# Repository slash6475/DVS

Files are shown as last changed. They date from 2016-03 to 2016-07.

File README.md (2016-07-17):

# DVS: Electronic Devil Stick
This project is an introduction to how to build quickly a native IP-based connected object on tiny platform. 
DVS is a simple electronic board composed of a 8 bits- microcontroller with Zigbee tranceiver, an accelerometer and some leds on child boards with an external button.
The software is implemented on Contiki OS, this micro-kernel dedicated to the Internet Of Thing allows 6LoWPAN networking (uIP stack with RPL for mesh network routing),
file system management to store data on flash or eeprom memories, shell interface over serial line, embedded webserver and more.

A simple Javascript page allows to design programs of RGB led sequences and to load them on the DVS platform over HTTP.
The programs are stored into the DVS file system and play on the leds according to the selected program by the external button.
In addition, the accelerometer and wireless communication can be used to control the leds. 
The wireless communication based on 6LoWPAN and HTTP can be operated by any other DVS platforms or computers.
Based on these features, a lot of scenarios and applications can be imagined. 



# Software
Contiki OS has a software architecture which facilitates the encapsulation of drivers and applications into independent containers.
Hence each component of DVS software is independent which facilitates implementation, modularity and code re-use.
Thanks to the shell over the serial line, it is possible to test the drivers of RGB leds and accelerometers, to manage the Webserver (start/stop) and the file system formating such as presented in following video.

(https://youtu.be/-myyth4NgPw)

## Shell Interface
Open the serial line over USB interface: 
```
minicom -D /dev/ttyUSB0 -b 19200
```
At booting time, different information on Contiki OS and DVS software configurations are provided such as networking, boot sequence, etc.
The command help provides the list of available commands:
```
neopixel test
neopixel ID_led R G B
mpu6050 start | stop
...
help
ps
kill
killall

```
## Programming
The software is implemented in C language and cross-platforms (MSP, AVR, ARM, X86, PIC, etc). The compilation must be executed in main project folder.
```
cd contiki-2.6/examples/dvs_main/
```
### Compilation
```
make all TARGET=avr-atmega128rfa1
avr-size --mcu=atmega128rfa1 dvs-main.avr-atmega128rfa1  -C
```

### Preparation
It is preferred to remove fuse and eeprom section to avoid to break fuse configuration and to erase programs stored in memories.
```
avr-objcopy -O ihex -R .eeprom -R .fuse -R .signature dvs-main.avr-atmega128rfa1 dvs-main.hex
```

### Loading
Example to load the program over ISP connector with a JTAG2 device.
```
sudo avrdude -p atmega128rfa1 -c jtag2isp -P usb -Uflash:w:dvs-main.hex
```
### 

## Arduino encapsulation
The DVS uses the accelerometer MPU6050 and the RGB leds Neopixel which have their librairy implemented in Arduino C++. 
Intead of implementing new librairies for Contiki OS, it is possible to link them dynamically at compilation step. 
Build a dvs.ino file with Arduino style and compile it, then remove the main.o and encapsulate it in a dynamic library.
More details in (contiki-2.6/apps/dvs)
```
avr-ar -cvq dvs_arduino.a *.o
```

In DVS Makefile of Contiki:
```
PROJECT_LIBRARIES=../../apps/dvs/libs/dvs_arduino.a
```

# Web Apps
The Web Interface is a simple javascript page which allows to generate and sequence chunk such as presented below. 
The number of program is not limited, however the sum of all sequences of all programs should be lower than file system size (4Kb).
Programs can be deleted individually, a long pressure on external button (> 20s) formats the file system.
```
OPERATION:TIME:RR1GG1BB1RR2GG2BB2 ...
add:0:001000000000000000000000ff0000ff0000000000000000000000000000000000000000ff0000ff0000000000000000000000
```



# Hardware

The master boards is composed of AVR Atmega128rfa1 with IEEE 802.15.4 radio transceiver, an accelerometer MPU6050 an an FTDI chipset for USB serial line. The external connectors provides pins to control Neopixel leds (16 in default child boards) and power stage of 4 AAAA batteries with their charger circuit based on LM317.
More detail and Eagle files in (/hardware).

## Scheme and PCB of Master Board



## Results



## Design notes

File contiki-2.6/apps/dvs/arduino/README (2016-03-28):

The arduino library should be compiled into an archive library .a and integrated during Contiki OS compilation.

1) Compile the arduino program by a traditionnal way
2) Get ALL object files, including ones of the libraries execpted the main.cpp.o because we will use one of Contiki
3) If some implemented functions in Arduino should be in Contiki, their prototype should be declared in extern "C" {} section of Arduino.h
4) Build the archive avr-ar -cvq dvs_arduino.a *.o
5) Move the archive libs folder to be included in Contiki compilation process thanks to Makefile.dvs

!! Trouble, some conflicts can occur about timers and other hardware component between Contiki and Arduino.

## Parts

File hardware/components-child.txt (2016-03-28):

Partlist

Exported from BatonDuDiable-leds.sch at 02/02/2016 17:00:40

EAGLE Version 7.4.0 Copyright (c) 1988-2015 CadSoft

Assembly variant: 

Part     Value          Device         Package         Library                    Sheet

BAT1                    BATTERYAAA-KIT BATTERY-AAA-KIT SparkFun-Electromechanical 1
BAT2                    BATTERYAAA-KIT BATTERY-AAA-KIT SparkFun-Electromechanical 1
LED1     WS2812B        WS2812B        WS2812B         WS2812                     1
LED2     WS2812B        WS2812B        WS2812B         WS2812                     1
LED3     WS2812B        WS2812B        WS2812B         WS2812                     1
LED4     WS2812B        WS2812B        WS2812B         WS2812                     1
LED5     WS2812B        WS2812B        WS2812B         WS2812                     1
LED6     WS2812B        WS2812B        WS2812B         WS2812                     1
LED7     WS2812B        WS2812B        WS2812B         WS2812                     1
LED8     WS2812B        WS2812B        WS2812B         WS2812                     1
SV1                     FE05-2W        FE05-2W         con-lsta                   1
SV2                     FE05-1         FE05-1          con-lsta                   1

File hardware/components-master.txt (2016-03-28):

Partlist

Exported from BatonDuDiable.brd at 02/02/2016 17:00:12

EAGLE Version 7.4.0 Copyright (c) 1988-2015 CadSoft

Assembly variant: 

Part      Value          Package           Library     Position (inch)       Orientation

A                        FE05-2W           con-lsta    (0.4 1.35)            R270
B                        FE05-2W           con-lsta    (2.75 1.35)           R90
B1        BALUN0805      BALUN             SparkFun    (2.45 1.5)            MR0
C1        1uF            C0603             rcl         (0.7 1.15)            R0
C2        0.1uF          0603-CAP          SparkFun    (0.7 1.25)            R0
C3        0.1uF          0603-CAP          SparkFun    (1.252 1.294)         MR90
C4        0.1uF          0603-CAP          SparkFun    (0.65 1.35)           R0
C5        10uF           0603-CAP          SparkFun    (1.95 1.25)           R270
C6        10 nF          0603-CAP          SparkFun    (1.672 1.575)         MR180
C7        1uF            0805              SparkFun    (1.25 1.5)            MR270
C8        1uF            0805              SparkFun    (1.15 1.5)            MR270
C9        12pF           0603-CAP          SparkFun    (0.9 1.2)             MR180
C10       12pF           0603-CAP          SparkFun    (1.1 1.2)             MR0
C11       12pF           0603-CAP          SparkFun    (1.9 1.2)             MR0
C12       12pF           0603-CAP          SparkFun    (1.9 1.3)             MR0
C13       22pF           0603-CAP          SparkFun    (2.3 1.5)             MR0
C14       22pF           0603-CAP          SparkFun    (2.45 1.35)           MR0
C15       0.47pF         0603-CAP          SparkFun    (2.45 1.2)            MR90
C16       4.7uF          0603-CAP          SparkFun    (0.85 1.5)            R90
C17       1uF            0805              SparkFun    (1.85 1.25)           R90
C18       0.1uF          0603-CAP          SparkFun    (0.8 1.35)            R0
C19       47 pF          0603-CAP          SparkFun    (0.7 1.25)            MR180
C20       47 pF          0603-CAP          SparkFun    (0.7 1.15)            MR180
IC1       FT230XQ        QFN16             ftdichip    (1 1.45)              R0
LED2                     CHIPLED_0603      led         (2.45 1.4)            R0
MICRO-USB USB-CONNECTOR  MICRO-USB-435-645 myrobotics2 (1 1.25)              R0
QUARTZ1   753-7203       753-7203          myrobotics2 (1 1.45)              MR90
QUARTZ2   QUARTZ32768    QUARTZ32768       myrobotics2 (1.9 1.4)             MR270
R1        10k            0603-RES          SparkFun    (2.05 1.5)            R180
R2        5.1K           0603-RES          SparkFun    (2.05 1.5)            MR270
R3        1.1k           R0603             rcl         (2.45 1.25)           R90
R4        5.1K           0603-RES          SparkFun    (2.15 1.5)            MR270
R50       10k            R0603             rcl         (1.85 1.45)           R90
R51       10             R0603             rcl         (0.8 1.35)            MR0
R53       10             R0603             rcl         (0.65 1.35)           MR0
SCL                      1X01              pinhead     (1.489 1.112)         R0
SDA                      1X01              pinhead     (1.589 1.112)         R0
SPI                      2X03              pinhead     (2.201 1.223)         R90
U$1       MPU-6050       QFN.24.4X4        MPU6050     (1.55 1.35)           MR0
U$7       MIC5366-2.8YMT SOT23-5           SparkFun    (0.7 1.5)             MR0
U1        ATMEGA128RFA1  QFN-64            SparkFun    (1.55 1.35)           R0
Y1        ANTENNA2SMD5   ANTENNA-CHIP5     SparkFun    (2.201 1.16)          MR0

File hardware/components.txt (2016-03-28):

Partlist

Exported from BatonDuDiable.brd at 16/02/2016 12:27:46

EAGLE Version 7.4.0 Copyright (c) 1988-2015 CadSoft

Assembly variant: 

Part      Value          Package           Library     Position (inch)       Orientation

V A                        FE05-2W           con-lsta    (0.4 1.35)            R270
V B                        FE05-2W           con-lsta    (2.75 1.35)           R90
V B1        BALUN0805      BALUN             SparkFun    (2.528 1.518)         MR0
C1        1uF            C0603             rcl         (0.724 1.202)         R270
V C2        0.1uF          0603-CAP          SparkFun    (0.598 1.198)         R90
V C3        0.1uF          0603-CAP          SparkFun    (1.235 1.235)         MR90
V C4        0.1uF          0603-CAP          SparkFun    (0.617 1.374)         R0
V C5        10uF           0603-CAP          SparkFun    (2.221 1.152)         R0
V C6        0.012uF           0603-CAP          SparkFun    (1.751 1.6)           MR180
C7        1uF            0805              SparkFun    (1.272 1.498)         MR270
C8        1uF            0805              SparkFun    (1.169 1.5)           MR270
V C9        12pF           0603-CAP          SparkFun    (0.9 1.2)             MR180
V C10       12pF           0603-CAP          SparkFun    (1.1 1.2)             MR0
V C11       12pF           0603-CAP          SparkFun    (1.9 1.2)             MR0
V C12       12pF           0603-CAP          SparkFun    (1.9 1.3)             MR0
V C13       22pF           0603-CAP          SparkFun    (2.366 1.55)          MR0
V C14       22pF           0603-CAP          SparkFun    (2.525 1.359)         MR0
V C15       0.47pF         0603-CAP          SparkFun    (2.53 1.201)          MR90
V C16       4.7uF          0603-CAP          SparkFun    (0.599 1.528)         R90    
C17       1uF            0805              SparkFun    (1.898 1.442)         R180
V C18       0.1uF          0603-CAP          SparkFun    (0.803 1.378)         R0
V C19       47 pF          0603-CAP          SparkFun    (0.598 1.199)         MR270
V C20       47 pF          0603-CAP          SparkFun    (0.725 1.202)         MR90
V IC1       FT230XQ        QFN16             ftdichip    (1.002 1.472)         R0
V LED2                     CHIPLED_0603      led         (2.534 1.387)         R0
V MICRO-USB USB-CONNECTOR  MICRO-USB-435-645 myrobotics2 (1 1.25)              R0
V QUARTZ1   753-7203       753-7203          myrobotics2 (0.998 1.492)         MR90
V QUARTZ2   QUARTZ32768    QUARTZ32768       myrobotics2 (2.014 1.254)         R0
V R1        10k            0603-RES          SparkFun    (2.051 1.55)          R90
V R2        5.1K           0603-RES          SparkFun    (2.052 1.552)         MR270
V R3        1.1k           R0603             rcl         (2.53 1.201)          R90
V R4        5.1K           0603-RES          SparkFun    (2.202 1.551)         MR270
V R50       10k            R0603             rcl         (1.9 1.441)           MR180
V R51       10             R0603             rcl         (0.803 1.378)         MR0
V R53       10             R0603             rcl         (0.616 1.373)         MR0
SCL                      1X01              pinhead     (1.489 1.112)         R0
SDA                      1X01              pinhead     (1.589 1.112)         R0
SPI                      2X03              pinhead     (2.221 1.35)          R180
V U$1       MPU-6050       QFN.24.4X4        MPU6050     (1.55 1.35)           MR0
V U$7       MIC5366-2.8YMT SOT23-5           SparkFun    (0.753 1.523)         MR0
V U1        ATMEGA128RFA1  QFN-64            SparkFun    (1.55 1.349)          R0
V Y1        ANTENNA2SMD5   ANTENNA-CHIP5     SparkFun    (2.23 1.155)          MR0

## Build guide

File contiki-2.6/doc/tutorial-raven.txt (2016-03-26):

/**
\addtogroup tutorials
@{
*/

/**
 * \defgroup tutorialraven Running Contiki with uIPv6 and SICSlowpan support on Atmel RAVEN hardware
 * @{
This tutorial explains how to run Contiki with IPv6 and 6lowpan
support on Atmel RAVEN hardware.

\section toc Table of contents
\ref introduction<br>
\ref hardware<br>
\ref software<br>
\ref overview<br>
\ref installation<br>
\ref running<br>
\ref advanced<br>
\ref issues<br>
\ref annex<br>

<HR>
\section introduction Introduction
This tutorial explains how to run Contiki with IPv6 and 6lowpan
support on Atmel RAVEN evaluation kit (ATAVRRZRAVEN) hardware. We
present basic example system architecture and application scenarios,
as well as instructions to run more advanced demos.

<HR>
\section hardware Hardware requirements

To run the demo, you will need at least
\li one AVR RAVEN board, which embeds an ATmega1284P and an
ATmega3290P micro controller (MCU) as well as an AT86RF230 
802.15.4 radio chip.
\li one RZ USB stick, which embeds an AT90USB1287 MCU and
an AT86RF230 802.15.4 radio chip.
\li one PC running Windows to program the chips. For the demo
itself, a PC running Linux or Windows.
\li one On-chip programming platform. We recommend Atmel JTAGICE
mkII.

\note Links to detailed hardware documentation are in
\ref annex_hardware

<HR>
\section software Software requirements
To install the demo you need:
\li Contiki 2.3 or later source code, installed in a directory. In 
the rest of this tutorial we assume the directory is c:/contiki
\li Cygwin with "make" utility installed.
\li AVR Studio 4.14 or later
\li WinAVR20080610 or later
\li Windows drivers installed for the JTAGICE mkII.

Instructions to install these tools are in the section \ref annex_software.<br>

To run the demo, you need:
\li one PC running Linux with kernel 2.6.24 or later, with support for the
following kernel modules: IPv6, usbnet, cdc_ether, cdc_acm, rndis_wlan.
\li OR one PC running Windows with IPv6 support. If you use Windows XP,
you need Service Pack 3 installed.

\note
On windows XP, if ipv6 support is not enabled, enable it by typing
in a shell:
\verbatim
ipv6 install
\endverbatim

<HR>
\section overview Demo Overview

\subsection overview_architecture Network Architecture
The network comprises:
\li a PC acting as an IPv6 router with an 802.15.4 interface
and an Ethernet interface.
\li a RAVEN board acting as an IPv6 host.

In the basic demo, you can:
\li Ping the RAVEN Board from the router
\li Ping the router from the RAVEN board, using the RAVEN board
menu
\li Browse the web server running on the RAVEN board. The server
displays the live temperature measured from the board temperature
sensor

\image html tutorial-raven-basic.jpg
<HR>
\section installation Compiling, installing, configuring

\subsection installation_compiling Compiling the binaries for RAVEN and RZ USB stick
The binaries needed are:
\li c:/contiki/examples/webserver-ipv6/webserver6.elf file for the RAVEN board ATmega1284P
\li c:/contiki/platform/avr-ravenlcd/ravenlcd_3290.elf file for the RAVEN board ATmega3290P
\li c:/contiki/examples/ravenusbstick/ravenusbstick.elf file for the RZ USB Stick AT90USB1287

To compile each of them, type in Cygwin:
\verbatim
cd c:/contiki/examples/webserver-ipv6-raven
make
\endverbatim
\verbatim
cd c:/contiki/platform/avr-ravenlcd
make
\endverbatim
\verbatim
cd c:/contiki/examples/ravenusbstick
make
\endverbatim

\subsection installation_hw Installing the hardware
To power the RAVEN, put the EXT/BAT jumper in BAT position.
This will enable power on batteries. If you want to power 
the RAVEN externally, check instructions in 
\ref advanced_externalboard.

The RZ USB Stick needs to be plugged in the PC you will run 
the demo on. If you plan to run the demo on a Windows PC, you
will need to install drivers once contiki is loaded on the 
stick. Until then, you can exit any driver installation popup.

\subsection installation_loading Programming the boards
<b>What you need to do</b><br>

\li On the RAVEN board, program the binaries on both AVR ATmega.
\li On the RZ USB Stick, load the binary on the AT90USB1287

<b>Hardware connections</b><br>
\li Connect the JTAG connectors to the JTAGICE as described in 
the picture below.

\image html tutorial-raven-jtag.jpg
\li Connect the JTAGICE mkII to a Windows PC through USB.
\li To program (load) each AVR, you will need to connect the 
JTAGICE JTAG connector to the JTAG pins corresponding to the 
AVR you want to program, as shown in the picture below.

\image html tutorial-raven-connections.jpg 

<b>To load the binary on each AVR in Windows</b><br>

\li Launch AVR Studio and exit any popup window.
\li Connect the JTAG pins of the JTAGICE into the JTAG connector of
the target processor.
\li In AVR Studio, click on "Tools"->"Program AVR"->"Auto Connect"
\li Go to the "Main tab"
\li In the "Programming mode and target settings" list, select JTAG
\li Select the processor type in the "Device" list and click
"Read Signature". If the Device signature is read properly,
it means AVR Studio is properly connected to the AVR.
\li Go to the "Program" tab
\li In the "ELF Production file format" section,
browse to the binary, then click program

\verbatim
For webserver6.elf, set the processor to ATmega1284P
For ravenlcd_3290.elf, set the processor to ATmega3290P
For ravenusbstick.elf, set the processor to AT90USB1287

\endverbatim

Once the RZ USB Stick is programmed, unplug it from the PC.
Note this programmed the fuses, EEPROM, and FLASH all at once.

<HR>
\section running Running the basic demo
\subsection running_router Setting up the router
<b>On Linux</b><br>
Plug the RZ USB Stick in the PC. It should appear as a USB
network interface (e.g. usb0).

usb0 should automatically get an IPv6 link local address, i.e. 
fe80::0012:13ff:fe14:1516/64. Check this is the case by typing 
\verbatim
ifconfig
\endverbatim
and checking the addresses of interface usb0

If it does not, add it manually:
\verbatim
ip -6 address add fe80::0012:13ff:fe14:1516/64 scope link dev usb0
\endverbatim

Configure the IP addresses on usb0
\verbatim
ip -6 address add aaaa::1/64 dev usb0
\endverbatim

Install the radvd deamon and configure it so the usb0
interface advertises the aaaa::/64 prefix as on link
and usable for address autoconfiguration.

Radvd configuration (usually in /etc/radvd.conf)
\verbatim
interface usb0
{
    AdvSendAdvert on;
    AdvLinkMTU 1280;
    AdvCurHopLimit 128;
    AdvReachableTime 360000;
    MinRtrAdvInterval 100;
    MaxRtrAdvInterval 150;
    AdvDefaultLifetime 200;
    prefix AAAA::/64
    {
        AdvOnLink on;
        AdvAutonomous on;
        AdvPreferredLifetime 4294967295; 
        AdvValidLifetime 4294967295; 
    };
};
\endverbatim
\note This values have been carefuly chosen to work on platform using
a 16bit clock.

Restart the radvd daemon. Example command:
\verbatim
/etc/init.d/radvd restart
\endverbatim

If you get a message that radvd won't start as forwarding isn't enabled,
you can run this as root:

\verbatim
echo 1 > /proc/sys/net/ipv6/conf/all/forwarding
\endverbatim

<b>On Windows</b><br>

Plug the RZ USB Stick in the PC. A "new hardware installation"
window should pop up. If it does not, go to "Control Panel"->
"Add Hardware". Choose "Install the driver manually", then
select the search path C:\\contiki\\cpu\\avr\\dev\\usb\\INF. Finish
the installation. 

You now need to get the "interface index" of the USB Stick 
interface (noted [interface index] in the following) and the 
Ethernet interface (noted [ethernet interface index] in the 
following).

In a DOS or Cygwin shell, type 
\verbatim
ipv6 if
\endverbatim

As an example, the output might look something like this:

\verbatim
...
Interface 7: Ethernet
 ...
 link-layer address: 02-12-13-14-15-16
 preferred link-local fe80::12:13ff:fe14:1516, life infinite
 ...
Interface 4: Ethernet: Local Area Connection
 ...
 link-layer address: 00-1e-37-16-5d-83
 preferred link-local fe80::21e:37ff:fe16:5d83, life infinite
 ...
...
\endverbatim

Note the link-layer address associated with interface 7 is the USB Stick. Hence
[interface index] is 7, [ethernet interface index] is 4 and [ethernet
link-local address] is fe80::21e:37ff:fe16:5d83.

Then you need to
\li Set the USB Stick interface as an advertising interface
\li Configure a global IP address on the USB Stick interface
\li Add a default route through the Ethernet interface
\li Set the aaaa::/64 prefix as "on link" and published on the USB Stick
interface.

To do so, type:
\code
ipv6 ifc [interface index] advertises forwards
ipv6 adu [interface index]/aaaa::1
ipv6 rtu ::/0 [ethernet interface index]/[ethernet link-local address] publish
ipv6 rtu aaaa::/64 [interface index] publish
\endcode

\subsection running_raven Booting the RAVEN boards

Reboot the RAVEN board.
The PC sends router advertisements and the RAVEN Board configures 
an IPv6 global address based on them. The PC global addresses 
were set above. Communication is ready.

\subsection running_ping1 Pinging the RAVEN board from the router
On Windows (Cygwin shell) or Linux, type
\verbatim
ping6 -n 5 aaaa::11:22ff:fe33:4455
\endverbatim
or
\verbatim
ping6 -s aaaa::1 aaaa::11:22ff:fe33:4455
\endverbatim
The router is sending 5 echo requests to the RAVEN board. The RAVEN board
answers with 5 echo replies.

\subsection running_ping2 Pinging the router from the RAVEN board
To send a ping from the RAVEN to the router you need to use the
RAVEN's joystick and LCD screen. Initially, the LCD screen should
print CONTIKI - 6LOWPAN in a loop. You can navigate the LCD menu by
using the small joystick just below its lower right corner. To 'ping'
push the joystick twice to the right. The RAVEN board sends 4 echo
requests to the router, which answers by 4 echo replies.<br>
For more information about the LCD menu, please see \ref lcdraven.

\subsection running_browse Browsing the RAVEN board web server
In a Web browser, point to http://[aaaa::0011:22ff:fe33:4455].
Then click on 'Sensor Readings'. If no temperature is displayed it
means that you need to start the temperature update %process on the
RAVEN. To do so you must use the RAVEN's LCD menu and
joystick. Starting from the CONTIKI - 6LOWPAN display navigate to TEMP
and then to SEND. You can pick either ONCE or AUTO, but in any
case you always need to reload the webpage to see the latest temperature
reading. <br>
For more information about the LCD menu, please see \ref lcdraven.

<HR>
\section advanced Advanced use
\subsection advanced_externalboard Using an external board for power and Debug
To power the RAVEN boards externally and enable debug output
on RS232, you can use the stk500 board together with the raven.

Power:
\li Set the 'EXT/BAT' jumper on the RAVEN board to EXT
\li Attach pin 2 on the bottom strip to GND of your STK500
\li Attach pin 1 on the bottom strip to VTG of your STK500
\li Power the STK500

Debug Connection
\li Attach pin 4 of the leftmost I/O header to pin 'TXD' on your STK500
\li Connect the STK500's "RS232SPARE" port to a RS232 port on a PC
\li Connect a terminal program (e.g. hyper terminal on Windows,
minicom on Linux) to the RS232 port on the PC at 57600 Baud,
with parity 8N1, no flow control
\li The raven board will output debug messages to the terminal

\note To enable specific debugging messages, edit the source
file you are interested in (e.g. core/net/uip-nd6-io.c for
Neighbor Discovery messages debug) and set the macro DEBUG to 1.
Then recompile the code, load the new binary on the board and
restart the RAVEN.

The following image shows this connection, with the red and black
being VCC and GND. The green wire is debug out:

\image html raven_detail.jpg

\note The output to the RS232 converts will only be about
3V, but they are expecting a signal swinging up to VTG, or by
default 5V. You may have to set VTG to 3.3V and power the Raven
from another source, making sure the GNDs of both the STK500
and your external source are connected together.

\subsection advanced_details Understanding the setup
There is no widely available 802.15.4 and 6lowpan stack for PCs.
As a temporary solution and to be able to connect IPv6 hosts
such as RAVEN boards to IP networks, we implemented a "bridge"
function on the RZ USB Stick. The RZ USB stick bridges 802.15.4
packets to Ethernet (The Ethernet interface is emulated on the
USB port).

As Ethernet frames and addresses are very different
from 802.15.4 ones, a few adjustements are needed on addresses
and some neighbor discovery packets. As a consequence, 802.15.4
MAC addresses configured on both the RAVEN boards and the RZ USB
stick must have the format:<br>
\verbatim
x2:xx:xx:ff:fe:xx:xx:xx
\endverbatim
where x can take any hexadecimal value.
Read the section below to change the MAC address on one device.

\subsection advanced_eeprom Change a device MAC address

You can change the MAC address of a RAVEN board or the RZ USB 
Stick by setting the 8 first bytes of the EEPROM, following 
the convention above. You can do this three ways. 

The first is to set EEPROM bytes directly in an AVR Studio project, in
Debug mode

\li compile the binary file for RAVEN, as explained in \ref installation
\li Connect the JTAG pins of the JTAGICE into the JTAG connector of
the target processor.
\li IN AVR Studio, go to File->open, select the binary just created
\li The Debug mode should start
\li Click on View->memory
\li select EEPROM in the menu, then just type in the first 8 bytes
the target MAC address

The second is to reprogram the whole EEPROM individually from the 
Flash and Fuses.

\li Connect the JTAG pins of the JTAGICE into the JTAG connector of
the target processor.
\li In AVR Studio, click on "Tools"->"Program AVR"->"Auto Connect"
\li Go to the "Program" tab
\li In the "EEPROM" section, click on "Read" and save the EEPROM 
content in a file (in hex format)
\li Edit this file with a text editor, change the value of the 
first 8 bytes, save
\li In the "EEPROM" section, check the path to the "Input Hex file"
is the one to the file you just modified and click on "Program". 

The third is to modify the default value in the code:

\li Edit the file contiki-raven-main.c in the directory
platform\avr-raven. You will see the MAC address set in a line like:

\code
/* Put default MAC address in EEPROM */
uint8_t mac_address[8] EEMEM = {0x02, 0x11, 0x22, 0xff, 0xfe, 0x33, 0x44, 0x55};
\endcode

\li Change this value, recompile and reprogram the elf on the board.

\subsection advanced_fuses Setting the fuses manually

In case you need to reset the fuses on one AVR, do the following:
\li In AVR Studio, click on "Tools"->"Program AVR"->"Auto Connect"
\li Go to the "Fuses" tab
\li In the lower part of the window, set the EXTENDED,
HIGH, LOW fuses to the following values
\verbatim
0xFF, 0x99, 0xE2 for the ATmega1284P on the RAVEN board
0xFF, 0x99, 0xE2 for the ATmega3290P on the RAVEN board
0xFB, 0x99, 0xDE for the AT90USB1287 on the USB Stick
\endverbatim
\li In the same tab, Click on "Program"
\subsection advanced_capture Observing packets with Atmel Wireless Services or Wireshark
To view packets being sent over the air, you can use Atmel AVR
Wireless Services in Sniffer Mode, with the RZ USB Stick. You need
the software preinstalled on the RZ USB Stick to do this. Packets
are sent on channel 24. Links to detailed information about
AVR Wireless Services is provided with the RZ USB Stick.

See the \ref usbstick documentation for more details about using Wireshark.

\subsection adavanced_linux Programming Flash, Fuses, EEPROM from a Linux machine

One can use avrdude to load the binaries in Linux.

\subsection advanced_hc01 Using HC01 Header Compression Scheme
IETF Internet Draft draft-hui-6lowpan-hc-01 defines a stateful
header compression mechanism (called HC01) which will soon
deprecate the stateless header compression mechanism (called
HC1) defined in RFC4944. HC01 is much more powerfull and flexible,
in particular it allows compression of some multicast addresses
and of all global unicast addresses.

Contiki is compiled by default with HC1 support. To use HC01
instead, edit platform/xxx/contiki-conf.h (replace xxx with avr-raven,
then avr-ravenusb.)
and replace the line<BR>
\code
#define SICSLOWPAN_CONF_COMPRESSION SICSLOWPAN_CONF_COMPRESSION_HC1
\endcode
with
\code
#define SICSLOWPAN_CONF_COMPRESSION SICSLOWPAN_CONF_COMPRESSION_HC01
\endcode

Recompile and load Contiki for both the RAVEN ATmega1284P and RZ USB 
Stick.

If you capture packets being sent over the air (on the 802.15.4
network), you will see that much more packets are compressed than
when HC1 is used. Overall, packets sent are much smaller.

\subsection advanced_network Building a more complete network
You can integrate the RAVEN boards and RZ USB stick to a more
complete IPv6 network by connecting the PC which you plug the RZ
USB Stick in to any IPv6 network with correct routing configured.

This way, you will be able to reach the RAVEN boards (to read
sensor data for example) from anywhere within this IPv6 network,
or even any IPv4 network if v4 to v6 translation mechanisms are
used between both networks.

You can also have several RAVEN boards in your setup. If you do so,
be sure to configure different MAC addresses on each board.

<HR>
\subsection issues Known issues
<b>RZ USB Stick Link local address not created on Linux</b><br>

When plugging the RZ USB Stick in a Linux PC, it should
automatically configure a link local address
(fe80::0012:13ff:fe14:1516/64 with default MAC address). On some Linux
distributions, it seems to fail. To check this, in a terminal,
type
\verbatim
ifconfig
\endverbatim
If the interface usb0 does not have an IPv6 address starting
with fe80::, add it manually by typing:
\verbatim
ip -6 address add fe80::0012:13ff:fe14:1516/64 scope link dev usb0
\endverbatim

<b>make version issues</b><br>
You need to use the "make" executable from WinAVR. There 
are compilation issues with GNU make coming with Cygwin.

<HR>
\section annex Annex

\subsection annex_contikiDocs Annex - Additional Documentation

\li USB Stick Platform:     \ref usbstick
\li User interface on Raven:\ref lcdraven
\li Wireless libraries for Atmel Radio: \ref wireless
\li MAC for Atmel Radio:    \ref macdoc
\li IPv6 Implementation: \ref uip6 
\li 6lowpan Implementation: \ref sicslowpan

\subsection annex_hardware Annex - Atmel products detailed documentation
<b>RAVEN evaluation and starter kits</b><br>
\li ATAVRRZRAVEN evaluation kit:
http://www.atmel.com/dyn/products/tools_card.asp?tool_id=4291
\li AVR RAVEN board:
http://www.atmel.com/dyn/products/tools_card.asp?tool_id=4395
\li RZ USB Stick:
http://www.atmel.com/dyn/products/tools_card.asp?tool_id=4396

<b>RAVEN AVRs and Wireless transceivers</b><br>
\li ATmega 1284P MegaAVR:
http://www.atmel.com/dyn/products/product_card.asp?part_id=4331
\li ATmega 3290P LCD AVR:
http://www.atmel.com/dyn/products/product_card.asp?part_id=4059
\li AT90USB1287 USB AVR:
http://www.atmel.com/dyn/products/product_card.asp?part_id=3875
\li AT86RF230 802.15.4 Transceiver:
http://www.atmel.com/dyn/products/product_card.asp?part_id=3941

<b>Additional hardware</b><br>
\li ATSTK500 evaluation kit
http://www.atmel.com/dyn/products/tools_card.asp?tool_id=2735
\li ATEVK1100 evaluation kit
http://www.atmel.com/dyn/products/tools_card.asp?tool_id=4114
\li AVR JTAGICE mkII debugging platform
http://www.atmel.com/dyn/products/tools_card.asp?tool_id=3353

<b>Buying the hardware (part number ATAVRRZRAVEN and ATJTAGICE2)</b><br>
\li For the U.S. you can use http://www.atmel.com/contacts/distributor_check.asp
\li Digikey http://www.digikey.com/
\li Spoerle http://www.spoerle.com/en/products 
\li Lawicel http://www.lawicel-shop.se

\subsection annex_software Software setup details
<b>Contiki</b><br>
Download Contiki code from http://www.sics.se/contiki and
extract the source code. We assume the directory you extract 
to is c:/contiki.

<b>Cygwin</b><br>
\li Download Cygwin from http://www.cygwin.com
\li Launch the setup executable
\li Follow the instructions until you reach the Window "Cygwin 
Setup - Select Packages"
\li In this window, expand the "Devel" item and 

<b>AVR Studio</b><br>
Download and install AVR Studio from
http://www.atmel.com/dyn/products/tools_card.asp?tool_id=2725

<b>WinAVR</b><br>
WinAVR which contains a number of AVR tools
such as the avr-gcc compiler.

Download and install WinAVR latest version from
http://winavr.sourceforge.net/ 

<b>JTAGICE mkII Drivers</b><br>
Plug the JTAGICE mkII in a USB port of a windows PC. Follow the
indications to install the Windows drivers automatically.

*/
/** @} */
/** @} */

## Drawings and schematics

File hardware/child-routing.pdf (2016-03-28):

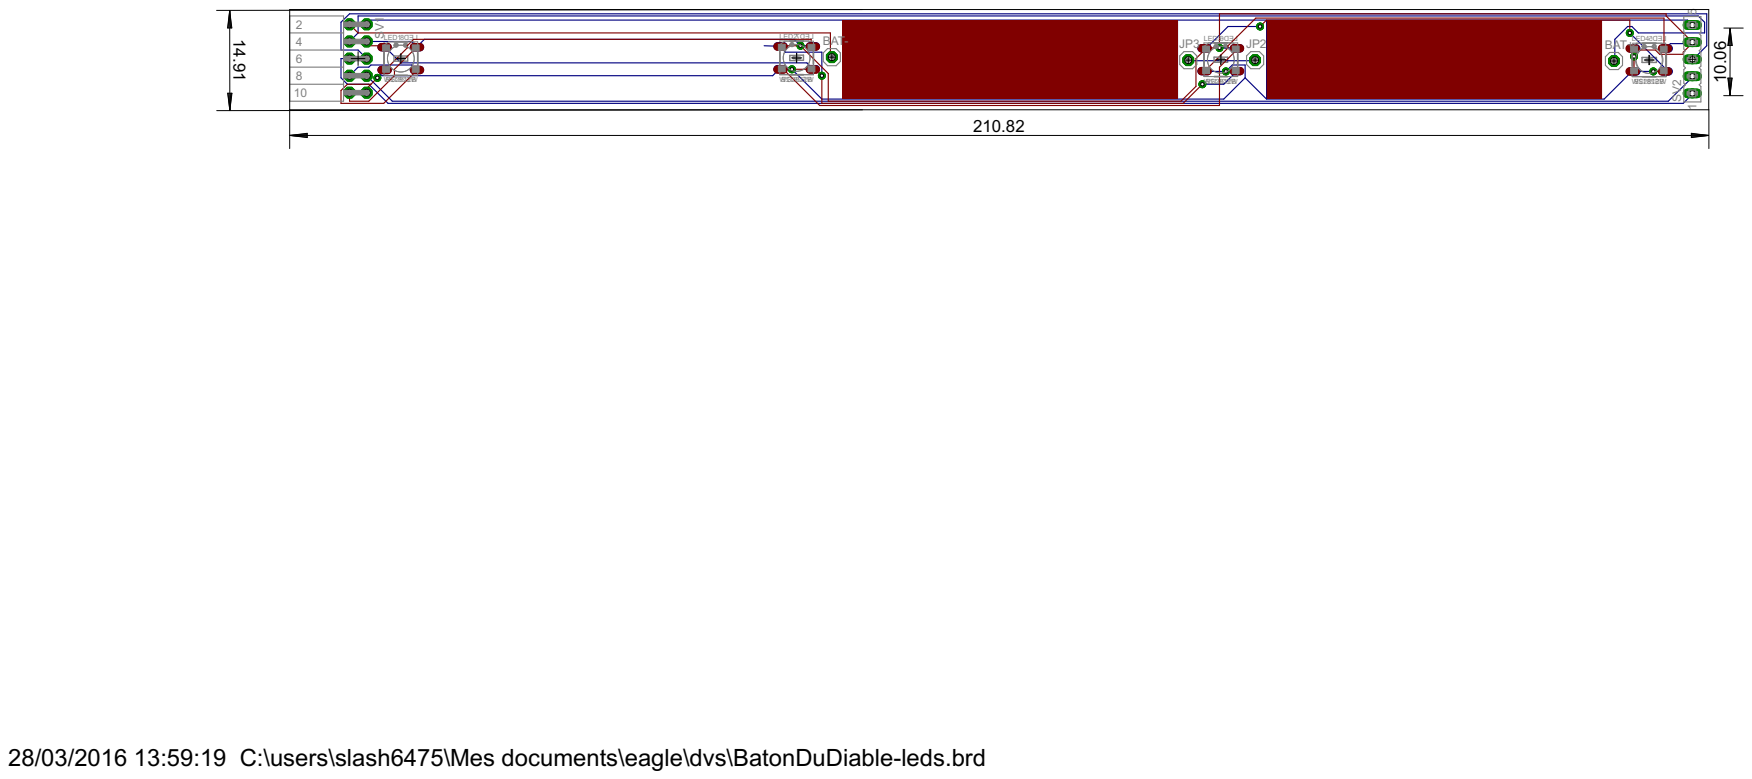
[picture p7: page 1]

28/03/2016 13:59:19 C:\users\slash6475\Mes documents\eagle\dvs\BatonDuDiable-leds.brd

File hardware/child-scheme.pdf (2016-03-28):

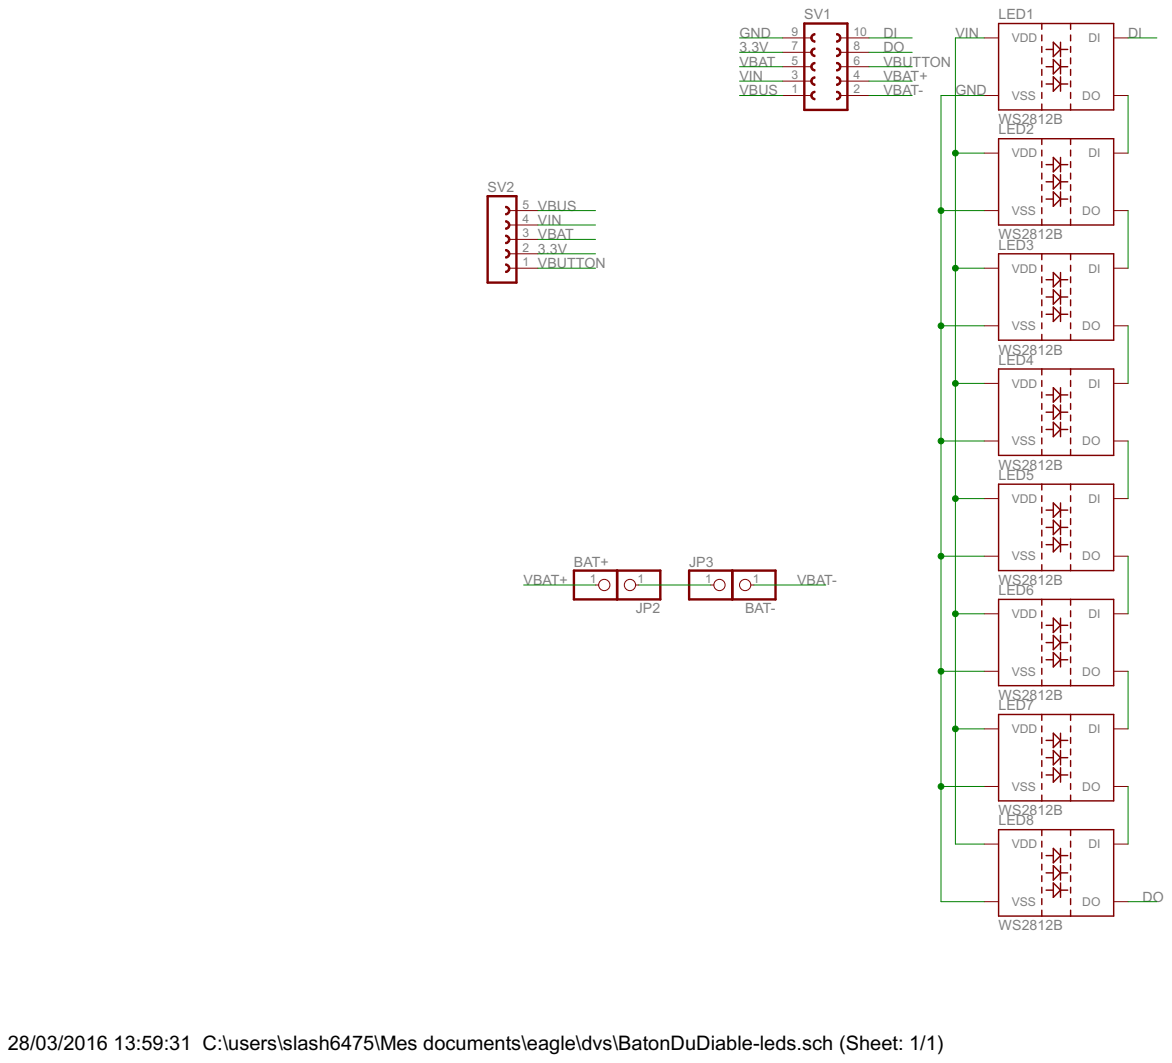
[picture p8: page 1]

28/03/2016 13:59:31 C:\users\slash6475\Mes documents\eagle\dvs\BatonDuDiable-leds.sch (Sheet: 1/1)

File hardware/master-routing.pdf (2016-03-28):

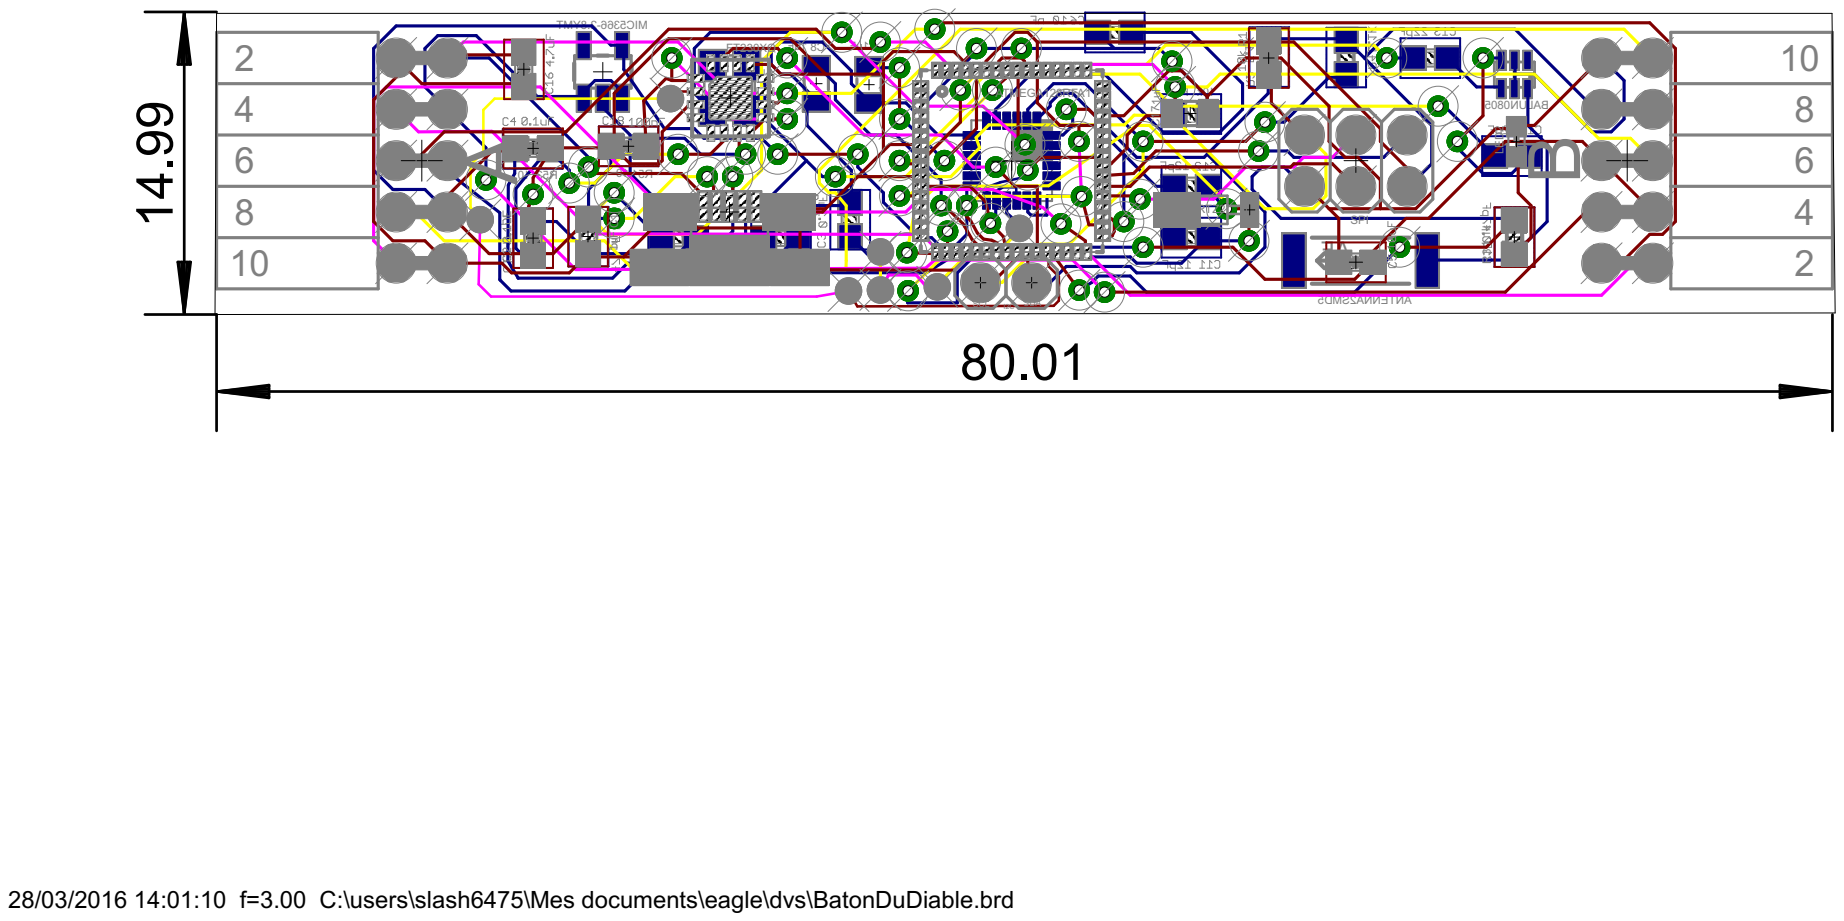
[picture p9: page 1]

28/03/2016 14:01:10 f=3.00 C:\users\slash6475\Mes documents\eagle\dvs\BatonDuDiable.brd

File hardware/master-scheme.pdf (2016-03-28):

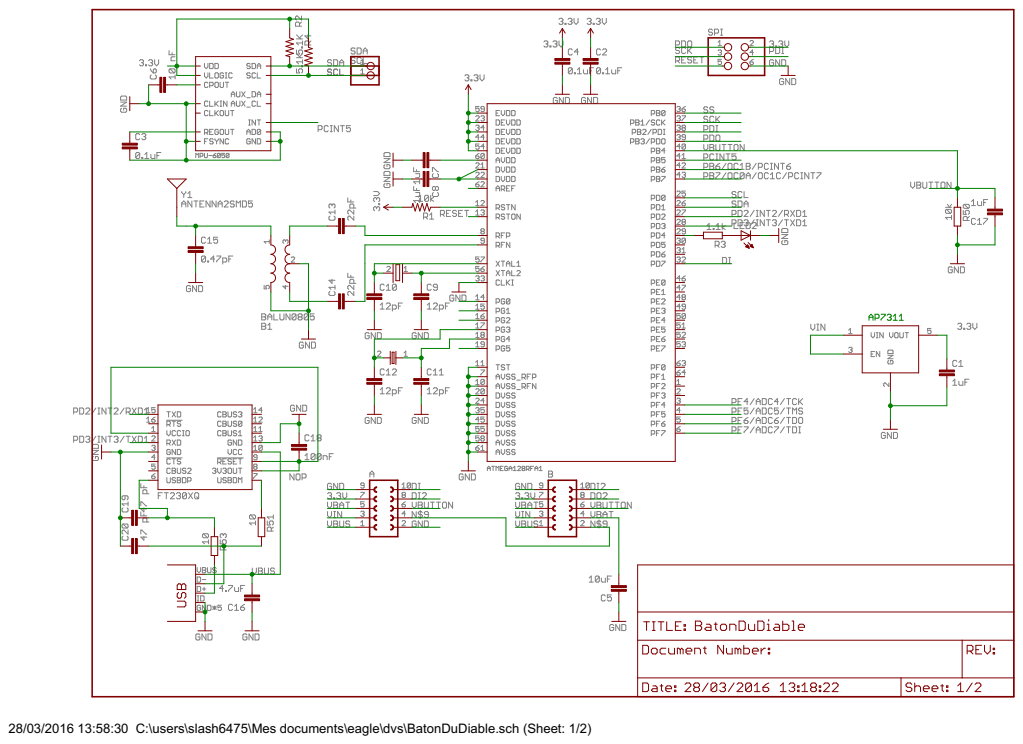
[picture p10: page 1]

28/03/2016 13:58:30 C:\users\slash6475\Mes documents\eagle\dvs\BatonDuDiable.sch (Sheet: 1/2)

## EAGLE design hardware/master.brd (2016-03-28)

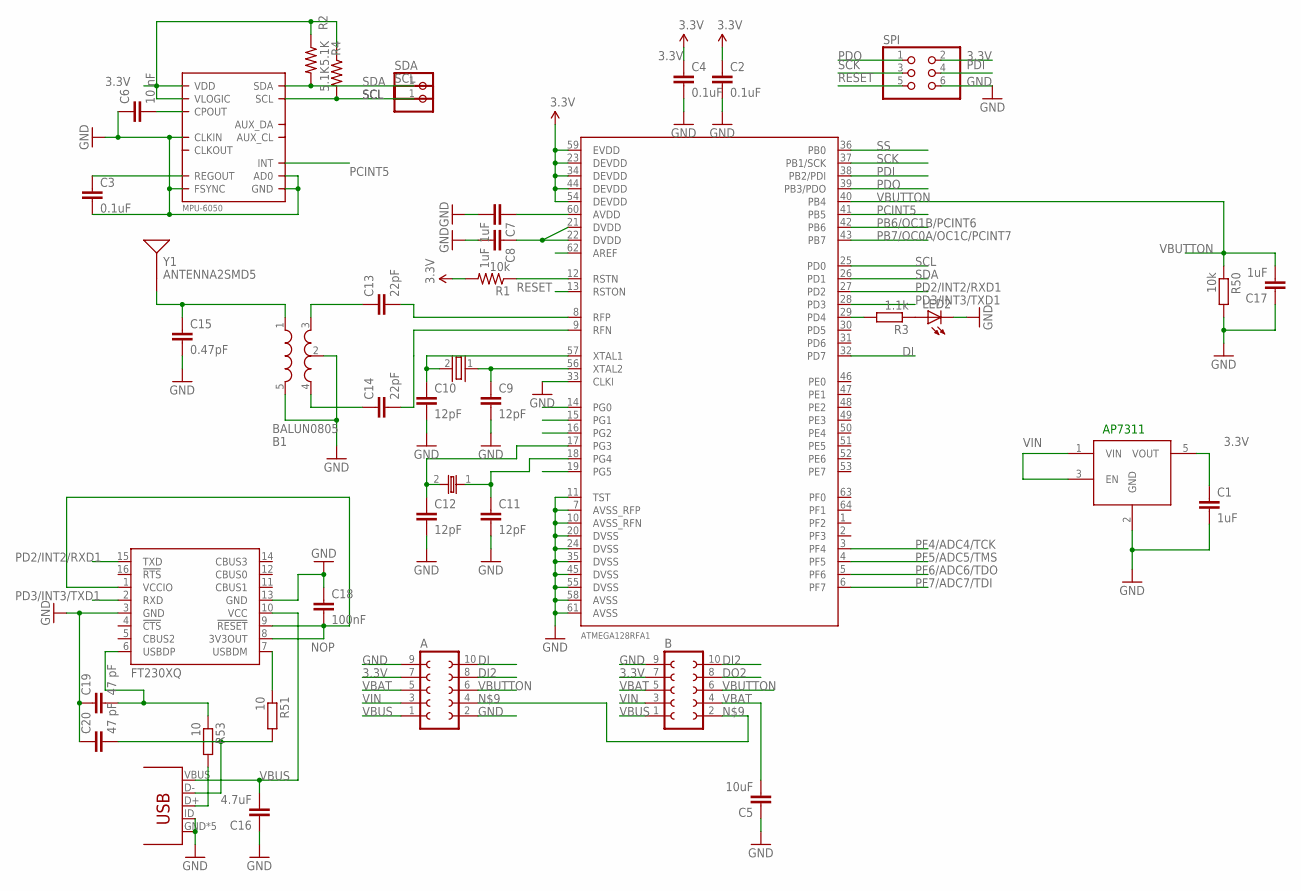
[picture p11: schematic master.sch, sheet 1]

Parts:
A: FE05-2W
B: FE05-2W
B1: BALUN0805; BALUN
C1: 1uF; C0603
C2, C3, C4: 0.1uF; 0603-CAP
C5: 10uF; 0603-CAP
C6: 10 nF; 0603-CAP
C7, C8, C17: 1uF; 0805
C9, C10, C11, C12: 12pF; 0603-CAP
C13, C14: 22pF; 0603-CAP
C15: 0.47pF; 0603-CAP
C16: 4.7uF; 0603-CAP
C18: 100nF; 0603-CAP
C19, C20: 47 pF; 0603-CAP
IC1: FT230XQ; QFN16
LED2: LEDCHIPLED_0603; CHIPLED_0603
MICRO-USB: USB-CONNECTOR; MICRO-USB-435-645
QUARTZ1: 753-7203
QUARTZ2: QUARTZ32768
R1: 10k; 0603-RES
R2, R4: 5.1K; 0603-RES
R3: 1.1k; R0603
R50: 10k; R0603
R51, R53: 10; R0603
SCL: PINHD-1X1; 1X01
SDA: PINHD-1X1; 1X01
SPI: PINHD-2X3; 2X03
U1: ATMEGA128RFA1; QFN-64
U$1: MPU-6050; QFN.24.4X4
U$7: MIC5366-2.8YMT; SOT23-5
Y1: ANTENNA2SMD5; ANTENNA-CHIP5

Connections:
3.3V: A.7, B.7, C1.1, C2.1, C4.1, R1.2, R2.1, R4.1, SPI.2, U1.23 (DEVDD), U1.34 (DEVDD), U1.44 (DEVDD), U1.54 (DEVDD), U1.59 (EVDD), U$1.8 (VLOGIC), U$1.13 (VDD), U$7.5 (VOUT)
AREF: U1.62 (AREF)
DI: A.10, U1.32 (PD7)
DI2: A.8, B.10
DO2: B.8
GND: A.2, A.9, B.9, B1.2 (GND), B1.5 (GND), C1.2, C2.2, C3.2, C4.2, C5.1, C6.1, C7.2, C8.2, C9.2, C10.2, C11.2, C12.2, C15.2, C16.1, C17.1, C18.1, C19.1, C20.1, IC1.3 (GND), IC1.13 (GND), LED2.C, MICRO-USB.GND, MICRO-USB.GND1 (GND), MICRO-USB.GND2 (GND), MICRO-USB.GND3 (GND), MICRO-USB.GND4 (GND), MICRO-USB.ID, R50.2, SPI.6, U1.7 (AVSS_RFP), U1.10 (AVSS_RFN), U1.11 (TST), U1.20 (DVSS), U1.24 (DVSS), U1.33 (CLKI), U1.35 (DVSS), U1.45 (DVSS), U1.55 (DVSS), U1.58 (AVSS), U1.61 (AVSS), U$1.1 (CLKIN), U$1.9 (AD0), U$1.11 (FSYNC), U$1.18 (GND), U$7.2 (GND)
unnamed: B1.3 (OUT1), C13.1
unnamed: B1.4 (OUT2), C14.1
unnamed: LED2.A, R3.1
unnamed: B1.1 (IN), C15.1, Y1.FEED
unnamed: C8.1, U1.21 (DVDD), U1.22 (DVDD)
unnamed: C14.2, U1.9 (RFN)
unnamed: C13.2, U1.8 (RFP)
unnamed: R3.2, U1.29 (PD4)
unnamed: A.4, B.2
unnamed: C7.1, U1.60 (AVDD)
unnamed: C3.1, U$1.10 (REGOUT)
unnamed: C10.1, QUARTZ1.2, U1.57 (XTAL1)
unnamed: C9.1, QUARTZ1.1, U1.56 (XTAL2)
unnamed: C12.1, QUARTZ2.2, U1.17 (PG3)
unnamed: C11.1, QUARTZ2.1, U1.18 (PG4)
unnamed: C6.2, U$1.20 (CPOUT)
unnamed: IC1.7 (USBDM), R51.1
unnamed: C20.2, MICRO-USB.D-, R51.2
unnamed: C19.2, IC1.6 (USBDP), R53.1
unnamed: MICRO-USB.D+, R53.2
NOP: C18.2, IC1.1 (VCCIO), IC1.8 (3V3OUT), IC1.9 (!RESET)
PB6/OC1B/PCINT6: U1.42 (PB6)
PB7/OC0A/OC1C/PCINT7: U1.43 (PB7)
PCINT5: U1.41 (PB5), U$1.12 (INT)
PD2/INT2/RXD1: IC1.15 (TXD), U1.27 (PD2)
PD3/INT3/TXD1: IC1.2 (RXD), U1.28 (PD3)
PDI: SPI.4, U1.38 (PB2/PDI)
PDO: SPI.1, U1.39 (PB3/PDO)
PF4/ADC4/TCK: U1.3 (PF4)
PF5/ADC5/TMS: U1.4 (PF5)
PF6/ADC6/TDO: U1.5 (PF6)
PF7/ADC7/TDI: U1.6 (PF7)
PG0: U1.14 (PG0)
PG1: U1.15 (PG1)
PG2: U1.16 (PG2)
PG5: U1.19 (PG5)
RESET: R1.1, SPI.5, U1.12 (RSTN)
RSTON: U1.13 (RSTON)
SCK: SPI.3, U1.37 (PB1/SCK)
SCL: R4.2, SCL.1, U1.25 (PD0), U$1.23 (SCL)
SDA: R2.2, SDA.1, U1.26 (PD1), U$1.24 (SDA)
SS: U1.36 (PB0)
VBAT: A.5, B.4, B.5, C5.2
VBUS: A.1, B.1, C16.2, IC1.10 (VCC), MICRO-USB.VBUS
VBUTTON: A.6, B.6, C17.2, R50.1, U1.40 (PB4)
VIN: A.3, B.3, U$7.1 (VIN), U$7.3 (EN)

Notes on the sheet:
AP7311

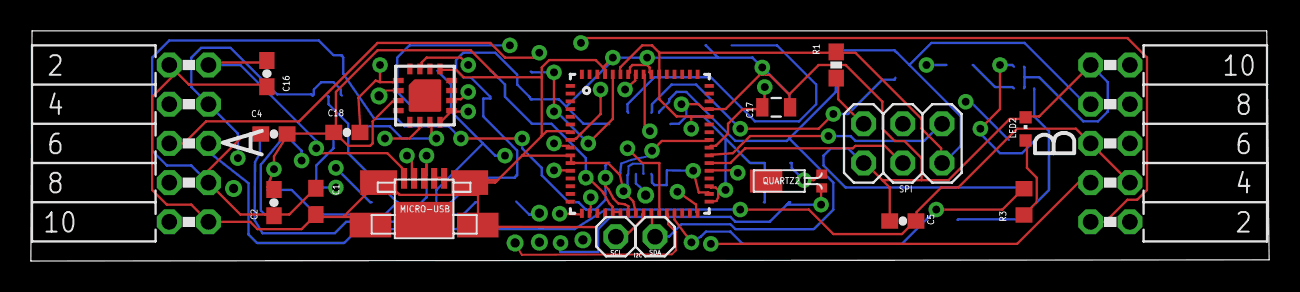
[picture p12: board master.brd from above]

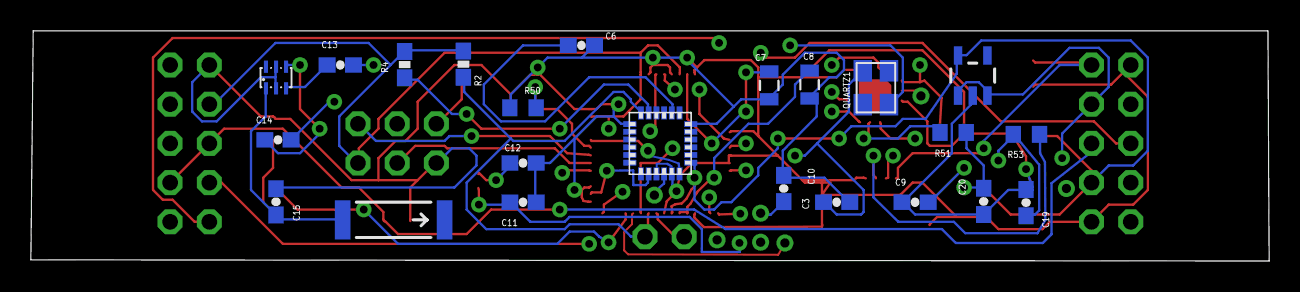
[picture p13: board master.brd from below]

Board: 4 copper layers, 80.2 x 14.9 mm, 42 parts (23 on the bottom side), 38 nets.

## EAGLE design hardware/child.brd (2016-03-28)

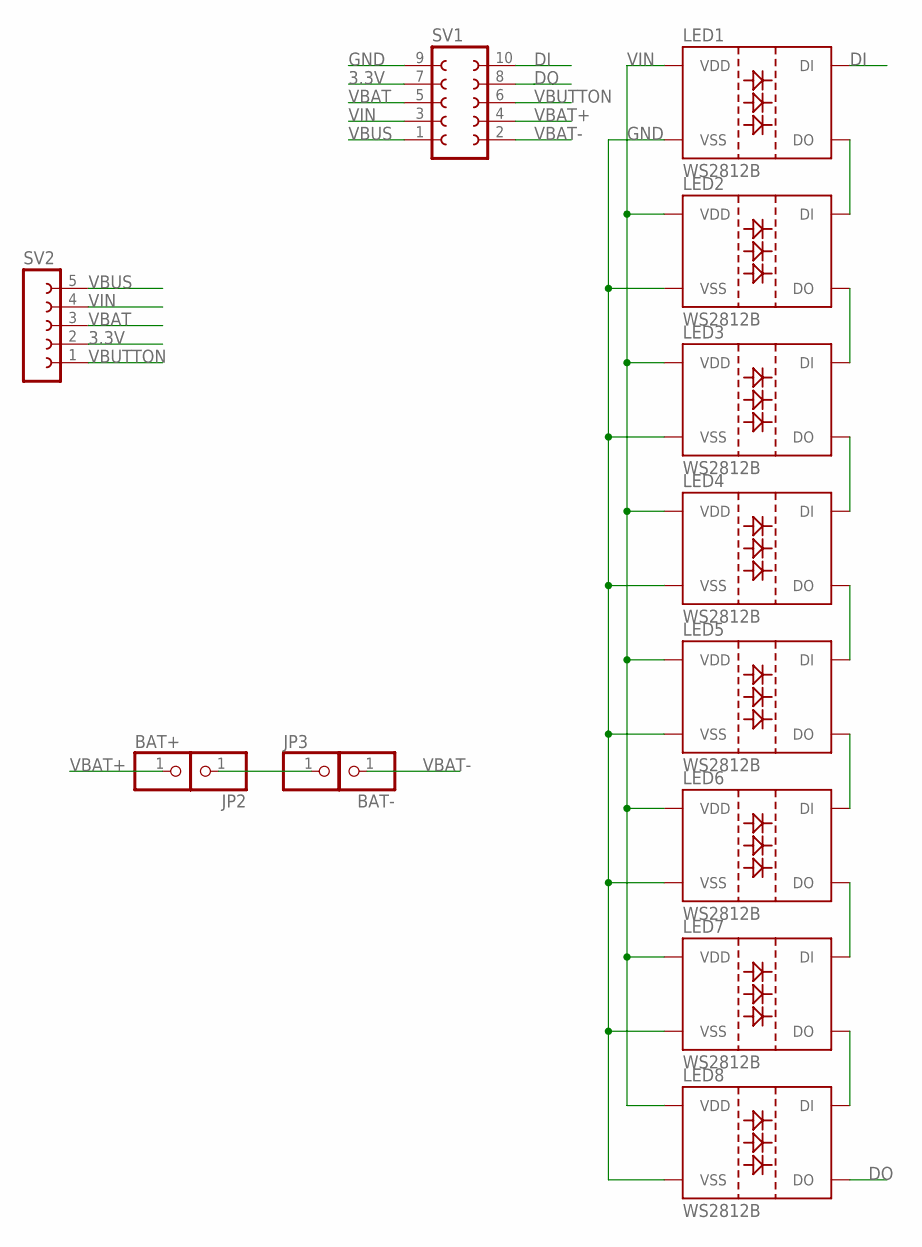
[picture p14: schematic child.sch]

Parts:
BAT+: PINHD-1X1; 1X01
BAT-: PINHD-1X1; 1X01
JP2, JP3: PINHD-1X1; 1X01
LED1, LED2, LED3, LED4, LED5, LED6, LED7, LED8: WS2812B
SV1: FE05-2W
SV2: FE05-1

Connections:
3.3V: SV1.7, SV2.2
DI: LED1.4 (DI), SV1.10
DO: LED8.2 (DO), SV1.8
GND: LED1.3 (VSS), LED2.3 (VSS), LED3.3 (VSS), LED4.3 (VSS), LED5.3 (VSS), LED6.3 (VSS), LED7.3 (VSS), LED8.3 (VSS), SV1.9
unnamed: LED1.2 (DO), LED2.4 (DI)
unnamed: LED2.2 (DO), LED3.4 (DI)
unnamed: LED3.2 (DO), LED4.4 (DI)
unnamed: LED4.2 (DO), LED5.4 (DI)
unnamed: LED5.2 (DO), LED6.4 (DI)
unnamed: LED6.2 (DO), LED7.4 (DI)
unnamed: LED7.2 (DO), LED8.4 (DI)
unnamed: JP2.1, JP3.1
VBAT: SV1.5, SV2.3
VBAT+: BAT+.1, SV1.4
VBAT-: BAT-.1, SV1.2
VBUS: SV1.1, SV2.5
VBUTTON: SV1.6, SV2.1
VIN: LED1.1 (VDD), LED2.1 (VDD), LED3.1 (VDD), LED4.1 (VDD), LED5.1 (VDD), LED6.1 (VDD), LED7.1 (VDD), LED8.1 (VDD), SV1.3, SV2.4

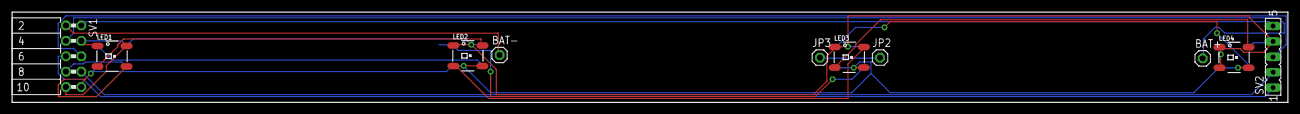
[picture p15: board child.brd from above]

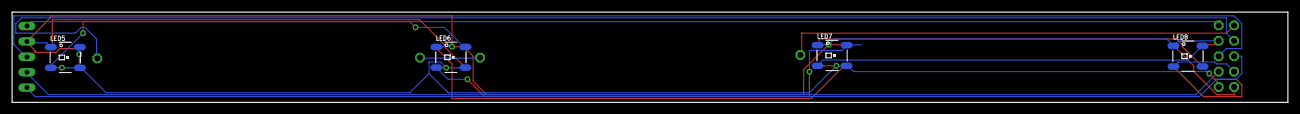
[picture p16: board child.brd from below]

Board: 4 copper layers, 210.8 x 14.9 mm, 14 parts (4 on the bottom side), 18 nets.

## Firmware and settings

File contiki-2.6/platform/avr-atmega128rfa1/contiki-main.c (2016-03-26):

/*
 * Copyright (c) 2006, Technical University of Munich
 * All rights reserved.
 *
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
 * This file is part of the Contiki operating system.
 *
 */
#define PRINTF(FORMAT,args...) printf_P(PSTR(FORMAT),##args)

#define ANNOUNCE_BOOT 1    //adds about 600 bytes to program size
#if ANNOUNCE_BOOT
#define PRINTA(FORMAT,args...) printf_P(PSTR(FORMAT),##args)
#else
#define PRINTA(...)
#endif

#define DEBUG 0
#if DEBUG
#define PRINTD(FORMAT,args...) printf_P(PSTR(FORMAT),##args)
#else
#define PRINTD(...)
#endif

#include <avr/pgmspace.h>
#include <avr/fuse.h>
#include <avr/eeprom.h>
#include <stdio.h>
#include <string.h>
#include <dev/watchdog.h>

#include "loader/symbols-def.h"
#include "loader/symtab.h"

#include "params.h"
#include "radio/rf230bb/rf230bb.h"
#include "net/mac/frame802154.h"
#include "net/mac/framer-802154.h"
#include "net/sicslowpan.h"

#include "contiki.h"
#include "contiki-net.h"
#include "contiki-lib.h"

#include "dev/rs232.h"
#include "dev/serial-line.h"
#include "dev/slip.h"

#ifdef RAVEN_LCD_INTERFACE
#include "raven-lcd.h"
#endif

#if AVR_WEBSERVER
#include "httpd-fs.h"
#include "httpd-cgi.h"
#endif

#ifdef COFFEE_FILES
#include "cfs/cfs.h"
#include "cfs/cfs-coffee.h"
#endif

#if UIP_CONF_ROUTER&&0
#include "net/routing/rimeroute.h"
#include "net/rime/rime-udp.h"
#endif

#include "net/rime.h"

/* Track interrupt flow through mac, rdc and radio driver */
//#define DEBUGFLOWSIZE 32
#if DEBUGFLOWSIZE
uint8_t debugflowsize,debugflow[DEBUGFLOWSIZE];
#define DEBUGFLOW(c) if (debugflowsize<(DEBUGFLOWSIZE-1)) debugflow[debugflowsize++]=c
#else
#define DEBUGFLOW(c)
#endif

/* Get periodic prints from idle loop, from clock seconds or rtimer interrupts */
/* Use of rtimer will conflict with other rtimer interrupts such as contikimac radio cycling */
/* STAMPS will print ENERGEST outputs if that is enabled. */
#define PERIODICPRINTS 1
#if PERIODICPRINTS
//#define PINGS 64
#define ROUTES 600
#define STAMPS 60
#define STACKMONITOR 1024
uint32_t clocktime;
#define TESTRTIMER 0
#if TESTRTIMER
uint8_t rtimerflag=1;
struct rtimer rt;
void rtimercycle(void) {rtimerflag=1;}
#endif
#endif

uint16_t ledtimer;

/*-------------------------------------------------------------------------*/
/*----------------------Configuration of the .elf file---------------------*/
#if 1
/* The proper way to set the signature is */
#include <avr/signature.h>
#else
/* Older avr-gcc's may not define the needed SIGNATURE bytes. Do it manually if you get an error */
typedef struct {const unsigned char B2;const unsigned char B1;const unsigned char B0;} __signature_t;
#define SIGNATURE __signature_t __signature __attribute__((section (".signature")))
SIGNATURE = {
  .B2 = 0x01,//SIGNATURE_2, //ATMEGA128rfa1
  .B1 = 0xA7,//SIGNATURE_1, //128KB flash
  .B0 = 0x1E,//SIGNATURE_0, //Atmel
};
#endif

#if 1
/* JTAG, SPI enabled, Internal RC osc, Boot flash size 4K, 6CK+65msec delay, brownout disabled */
FUSES ={.low = 0xe2, .high = 0x99, .extended = 0xff,};
#else
/* JTAG+SPI, Boot 4096 words @ $F000, Internal  oscillator, startup 6 CK +0 ms, Brownout 1.8 volts */
FUSES ={.low = 0xC2, .high = 0x99, .extended = 0xfe,};
#endif

uint8_t
rng_get_uint8(void) {
#if 1
  /* Upper two RSSI reg bits (RND_VALUE) are random in rf231 */
  uint8_t j;
  j = (PHY_RSSI&0xc0) + ((PHY_RSSI>>2)&0x30) + ((PHY_RSSI>>4)&0x0c) + ((PHY_RSSI>>6)&0x03);
#else
/* Get a pseudo random number using the ADC */
  uint8_t i,j;
  ADCSRA=1<<ADEN;             //Enable ADC, not free running, interrupt disabled, fastest clock
  for (i=0;i<4;i++) {
    ADMUX = 0;                //toggle reference to increase noise
    ADMUX =0x1E;              //Select AREF as reference, measure 1.1 volt bandgap reference.
    ADCSRA|=1<<ADSC;          //Start conversion
    while (ADCSRA&(1<<ADSC)); //Wait till done
	j = (j<<2) + ADC;
  }
  ADCSRA=0;                   //Disable ADC
#endif
  PRINTD("rng issues %d\n",j);
  return j;
}

/*-------------------------Low level initialization------------------------*/
/*------Done in a subroutine to keep main routine stack usage small--------*/
void initialize(void)
{
//  watchdog_init();
//  watchdog_start();

/* The Raven implements a serial command and data interface via uart0 to a 3290p,
 * which could be duplicated using another host computer.
 */



  rs232_init(RS232_PORT_1, USART_BAUD_19200,USART_PARITY_NONE | USART_STOP_BITS_1 | USART_DATA_BITS_8);
  rs232_redirect_stdout(RS232_PORT_1);
  rs232_set_input(RS232_PORT_1, serial_line_input_byte);



  clock_init();

  if(MCUSR & (1<<PORF )) PRINTD("Power-on reset.\n");
  if(MCUSR & (1<<EXTRF)) PRINTD("External reset!\n");
  if(MCUSR & (1<<BORF )) PRINTD("Brownout reset!\n");
  if(MCUSR & (1<<WDRF )) PRINTD("Watchdog reset!\n");
  if(MCUSR & (1<<JTRF )) PRINTD("JTAG reset!\n");

#if STACKMONITOR
  /* Simple stack pointer highwater monitor. Checks for magic numbers in the main
   * loop. In conjuction with PERIODICPRINTS, never-used stack will be printed
   * every STACKMONITOR seconds.
   */
{
extern uint16_t __bss_end;
uint16_t p=(uint16_t)&__bss_end;
    do {
      *(uint16_t *)p = 0x4242;
      p+=10;
    } while (p<SP-10); //don't overwrite our own stack
}
#endif

#define CONF_CALIBRATE_OSCCAL 0
#if CONF_CALIBRATE_OSCCAL
void calibrate_rc_osc_32k();
{
extern uint8_t osccal_calibrated;
uint8_t i;
  PRINTD("\nBefore calibration OSCCAL=%x\n",OSCCAL);
  for (i=0;i<10;i++) {
    calibrate_rc_osc_32k();
    PRINTD("Calibrated=%x\n",osccal_calibrated);
//#include <util/delay_basic.h>
//#define delay_us( us )   ( _delay_loop_2(1+(us*F_CPU)/4000000UL) )
//   delay_us(50000);
 }
   clock_init();
}
#endif

  PRINTA("\n*******Booting %s*******\n",CONTIKI_VERSION_STRING);

/* rtimers needed for radio cycling */
  rtimer_init();

 /* Initialize process subsystem */
  process_init();

  /* etimers must be started before ctimer_init */
  process_start(&etimer_process, NULL);
  ctimer_init();

  /* Start radio and radio receive process */
  NETSTACK_RADIO.init();

/* Get a random seed for the 802.15.4 packet sequence number.
 * Some layers will ignore duplicates found in a history (e.g. Contikimac)
 * causing the initial packets to be ignored after a short-cycle restart.
 */
  random_init(rng_get_uint8());

  /* Set addresses BEFORE starting tcpip process */

  rimeaddr_t addr;

  if (params_get_eui64(addr.u8)) {
      PRINTA("Random EUI64 address generated\n");
  }

#if UIP_CONF_IPV6
  memcpy(&uip_lladdr.addr, &addr.u8, sizeof(rimeaddr_t));
#elif WITH_NODE_ID
  node_id=get_panaddr_from_eeprom();
  addr.u8[1]=node_id&0xff;
  addr.u8[0]=(node_id&0xff00)>>8;
  PRINTA("Node ID from eeprom: %X\n",node_id);
#endif
  rimeaddr_set_node_addr(&addr);

  rf230_set_pan_addr(params_get_panid(),params_get_panaddr(),(uint8_t *)&addr.u8);
  rf230_set_channel(params_get_channel());
  rf230_set_txpower(params_get_txpower());

#if UIP_CONF_IPV6
  PRINTA("EUI-64 MAC: %x-%x-%x-%x-%x-%x-%x-%x\n",addr.u8[0],addr.u8[1],addr.u8[2],addr.u8[3],addr.u8[4],addr.u8[5],addr.u8[6],addr.u8[7]);
#else
  PRINTA("MAC address ");
  uint8_t i;
  for (i=sizeof(rimeaddr_t); i>0; i--){
    PRINTA("%x:",addr.u8[i-1]);
  }
  PRINTA("\n");
#endif

  /* Initialize stack protocols */
  queuebuf_init();
  NETSTACK_RDC.init();
  NETSTACK_MAC.init();
  NETSTACK_NETWORK.init();

#if ANNOUNCE_BOOT
  PRINTA("%s %s, channel %u , check rate %u Hz tx power %u\n",NETSTACK_MAC.name, NETSTACK_RDC.name, rf230_get_channel(),
    CLOCK_SECOND / (NETSTACK_RDC.channel_check_interval() == 0 ? 1:NETSTACK_RDC.channel_check_interval()),
    rf230_get_txpower());
#if UIP_CONF_IPV6_RPL
  PRINTA("RPL Enabled\n");
#endif
#if UIP_CONF_ROUTER
  PRINTA("Routing Enabled\n");
#endif

#endif /* ANNOUNCE_BOOT */

  process_start(&tcpip_process, NULL);

#ifdef RAVEN_LCD_INTERFACE
  process_start(&raven_lcd_process, NULL);
#endif

  /* Autostart other processes */
  autostart_start(autostart_processes);

  /*---If using coffee file system create initial web content if necessary---*/

#if 0
  int fa = cfs_open( "/index.html", CFS_READ);
  if (fa<0) {     //Make some default web content
    PRINTA("No index.html file found, creating upload.html!\n");
    PRINTA("Formatting FLASH file system for coffee...");
    cfs_coffee_format();
    PRINTA("Done!\n");
    fa = cfs_open( "/index.html", CFS_WRITE);
    int r = cfs_write(fa, &"It works!", 9);
    if (r<0) PRINTA("Can''t create /index.html!\n");
    cfs_close(fa);
//  fa = cfs_open("upload.html"), CFW_WRITE);
// <html><body><form action="upload.html" enctype="multipart/form-data" method="post"><input name="userfile" type="file" size="50" /><input value="Upload" type="submit" /></form></body></html>
  }
#endif /* COFFEE_FILES */

/* Add addresses for testing */
#if 0
{
  uip_ip6addr_t ipaddr;
  uip_ip6addr(&ipaddr, 0xaaaa, 0, 0, 0, 0, 0, 0, 0);
  uip_ds6_addr_add(&ipaddr, 0, ADDR_AUTOCONF);
//  uip_ds6_prefix_add(&ipaddr,64,0);
}
#endif

/*--------------------------Announce the configuration---------------------*/
#if ANNOUNCE_BOOT
#if AVR_WEBSERVER
{ uint8_t i;
  char buf[80];
  unsigned int size;

  for (i=0;i<UIP_DS6_ADDR_NB;i++) {
	if (uip_ds6_if.addr_list[i].isused) {
	   httpd_cgi_sprint_ip6(uip_ds6_if.addr_list[i].ipaddr,buf);
       PRINTA("IPv6 Address: %s\n",buf);
	}
  }
   cli();
   eeprom_read_block (buf,eemem_server_name, sizeof(eemem_server_name));
   sei();
   buf[sizeof(eemem_server_name)]=0;
   PRINTA("%s",buf);
   cli();
   eeprom_read_block (buf,eemem_domain_name, sizeof(eemem_domain_name));
   sei();
   buf[sizeof(eemem_domain_name)]=0;
   size=httpd_fs_get_size();
#ifndef COFFEE_FILES
   PRINTA(".%s online with fixed %u byte web content\n",buf,size);
#elif COFFEE_FILES==1
   PRINTA(".%s online with static %u byte EEPROM file system\n",buf,size);
#elif COFFEE_FILES==2
   PRINTA(".%s online with dynamic %u KB EEPROM file system\n",buf,size>>10);
#elif COFFEE_FILES==3
   PRINTA(".%s online with static %u byte program memory file system\n",buf,size);
#elif COFFEE_FILES==4
   PRINTA(".%s online with dynamic %u KB program memory file system\n",buf,size>>10);
#endif /* COFFEE_FILES */
}
#else
   PRINTA("Online\n");
#endif
#endif /* ANNOUNCE_BOOT */

#if RF230BB_CONF_LEDONPORTE1
  /* NB: PORTE1 conflicts with UART0 */
  DDRE|=(1<<DDE1);  //set led pin to output (Micheal Hatrtman board)
  PORTE&=~(1<<PE1); //and low to turn led off
#endif
}

#if ROUTES && UIP_CONF_IPV6
static void
ipaddr_add(const uip_ipaddr_t *addr)
{
  uint16_t a;
  int8_t i, f;
  for(i = 0, f = 0; i < sizeof(uip_ipaddr_t); i += 2) {
    a = (addr->u8[i] << 8) + addr->u8[i + 1];
    if(a == 0 && f >= 0) {
      if(f++ == 0) PRINTF("::");
    } else {
      if(f > 0) {
        f = -1;
      } else if(i > 0) {
        PRINTF(":");
      }
      PRINTF("%x",a);
    }
  }
}
#endif

/*-------------------------------------------------------------------------*/
/*------------------------- Main Scheduler loop----------------------------*/
/*-------------------------------------------------------------------------*/
int
main(void)
{
  initialize();

  while(1) {
    process_run();
//    watchdog_periodic();

    /* Turn off LED after a while */
    if (ledtimer) {
      if (--ledtimer==0) {
#if RF230BB_CONF_LEDONPORTE1
        PORTE&=~(1<<PE1);
#endif
#if defined(RAVEN_LCD_INTERFACE)&&0
       /* ledtimer can be set by received ping; ping the other way for testing */
       extern void raven_ping6(void);
       raven_ping6();
#endif
      }
    }

#if 0
/* Various entry points for debugging in the AVR Studio simulator.
 * Set as next statement and step into the routine.
 */
    NETSTACK_RADIO.send(packetbuf_hdrptr(), 42);
    process_poll(&rf230_process);
    packetbuf_clear();
    len = rf230_read(packetbuf_dataptr(), PACKETBUF_SIZE);
    packetbuf_set_datalen(42);
    NETSTACK_RDC.input();
#endif

#if 0
/* Clock.c can trigger a periodic PLL calibration in the RF230BB driver.
 * This can show when that happens.
 */
    extern uint8_t rf230_calibrated;
    if (rf230_calibrated) {
      PRINTD("\nRF230 calibrated!\n");
      rf230_calibrated=0;
    }
#endif

/* Set DEBUGFLOWSIZE in contiki-conf.h to track path through MAC, RDC, and RADIO */
#if DEBUGFLOWSIZE
  if (debugflowsize) {
    debugflow[debugflowsize]=0;
    PRINTF("%s",debugflow);
    debugflowsize=0;
   }
#endif

#if PERIODICPRINTS
#if TESTRTIMER
/* Timeout can be increased up to 8 seconds maximum.
 * A one second cycle is convenient for triggering the various debug printouts.
 * The triggers are staggered to avoid printing everything at once.
 */
    if (rtimerflag) {
      rtimer_set(&rt, RTIMER_NOW()+ RTIMER_ARCH_SECOND*1UL, 1,(void *) rtimercycle, NULL);
      rtimerflag=0;
#else
  if (clocktime!=clock_seconds()) {
     clocktime=clock_seconds();
#endif

#if STAMPS
if ((clocktime%STAMPS)==0) {
#if ENERGEST_CONF_ON
#include "lib/print-stats.h"
	print_stats();
#elif RADIOSTATS
extern volatile unsigned long radioontime;
  PRINTF("%u(%u)s\n",clocktime,radioontime);
#else
  PRINTF("%us\n",clocktime);
#endif

}
#endif
#if TESTRTIMER
      clocktime+=1;
#endif

#if PINGS && UIP_CONF_IPV6
extern void raven_ping6(void);
if ((clocktime%PINGS)==1) {
  PRINTF("**Ping\n");
  raven_ping6();
}
#endif

#if ROUTES && UIP_CONF_IPV6
if ((clocktime%ROUTES)==2) {

extern uip_ds6_nbr_t uip_ds6_nbr_cache[];
extern uip_ds6_route_t uip_ds6_routing_table[];
extern uip_ds6_netif_t uip_ds6_if;

  uint8_t i,j;
  PRINTF("\nAddresses [%u max]\n",UIP_DS6_ADDR_NB);
  for (i=0;i<UIP_DS6_ADDR_NB;i++) {
    if (uip_ds6_if.addr_list[i].isused) {
      ipaddr_add(&uip_ds6_if.addr_list[i].ipaddr);
      PRINTF("\n");
    }
  }
  PRINTF("\nNeighbors [%u max]\n",UIP_DS6_NBR_NB);
  for(i = 0,j=1; i < UIP_DS6_NBR_NB; i++) {
    if(uip_ds6_nbr_cache[i].isused) {
      ipaddr_add(&uip_ds6_nbr_cache[i].ipaddr);
      PRINTF("\n");
      j=0;
    }
  }
  if (j) PRINTF("  <none>");
  PRINTF("\nRoutes [%u max]\n",UIP_DS6_ROUTE_NB);
  for(i = 0,j=1; i < UIP_DS6_ROUTE_NB; i++) {
    if(uip_ds6_routing_table[i].isused) {
      ipaddr_add(&uip_ds6_routing_table[i].ipaddr);
      PRINTF("/%u (via ", uip_ds6_routing_table[i].length);
      ipaddr_add(&uip_ds6_routing_table[i].nexthop);
 //     if(uip_ds6_routing_table[i].state.lifetime < 600) {
        PRINTF(") %lus\n", uip_ds6_routing_table[i].state.lifetime);
 //     } else {
 //       PRINTF(")\n");
 //     }
      j=0;
    }
  }
  if (j) PRINTF("  <none>");
  PRINTF("\n---------\n");
}
#endif

#if STACKMONITOR
if ((clocktime%STACKMONITOR)==3) {
  extern uint16_t __bss_end;
  uint16_t p=(uint16_t)&__bss_end;
  do {
    if (*(uint16_t *)p != 0x4242) {
      PRINTF("Never-used stack > %d bytes\n",p-(uint16_t)&__bss_end);
      break;
    }
    p+=10;
  } while (p<RAMEND-10);
}
#endif

    }
#endif /* PERIODICPRINTS */

#if RF230BB&&0
extern uint8_t rf230processflag;
    if (rf230processflag) {
      PRINTF("rf230p%d",rf230processflag);
      rf230processflag=0;
    }
#endif

#if RF230BB&&0
extern uint8_t rf230_interrupt_flag;
    if (rf230_interrupt_flag) {
 //   if (rf230_interrupt_flag!=11) {
        PRINTF("**RI%u",rf230_interrupt_flag);
 //   }
      rf230_interrupt_flag=0;
    }
#endif
  }
  return 0;
}

/*---------------------------------------------------------------------------*/

void log_message(char *m1, char *m2)
{
  PRINTF("%s%s\n", m1, m2);
}

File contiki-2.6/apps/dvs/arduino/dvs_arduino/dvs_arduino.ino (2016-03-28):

#ifndef _H_dvs_arudio
  #define _H_dvs_arudio
  #include <Adafruit_NeoPixel.h>
  #ifdef __AVR__
    #include <avr/power.h>
  #endif
  
  // Neopixel
  #define PIN            38
  #define NUMPIXELS      16
  Adafruit_NeoPixel pixels = Adafruit_NeoPixel(NUMPIXELS, PIN, NEO_GRB + NEO_KHZ800);
  int delayval = 500; // delay for half a second
  uint8_t r,g,b;
  
  // MPU6050
  #include "I2Cdev.h"
  #include "MPU6050_6Axis_MotionApps20.h"
  #if I2CDEV_IMPLEMENTATION == I2CDEV_ARDUINO_WIRE
      #include "Wire.h"
  #endif
  MPU6050 mpu;
  #define OUTPUT_READABLE_YAWPITCHROLL
  // MPU control/status vars
  uint8_t mpuIntStatus;   // holds actual interrupt status byte from MPU
  uint8_t devStatus = -1;      // return status after each device operation (0 = success, !0 = error)
  uint16_t packetSize;    // expected DMP packet size (default is 42 bytes)
  uint16_t fifoCount;     // count of all bytes currently in FIFO
  uint8_t fifoBuffer[64]; // FIFO storage buffer
  
  // orientation/motion vars
  Quaternion q;           // [w, x, y, z]         quaternion container
  VectorInt16 aa;         // [x, y, z]            accel sensor measurements
  VectorInt16 aaReal;     // [x, y, z]            gravity-free accel sensor measurements
  VectorInt16 aaWorld;    // [x, y, z]            world-frame accel sensor measurements
  VectorFloat gravity;    // [x, y, z]            gravity vector
  float euler[3];         // [psi, theta, phi]    Euler angle container
  float ypr[3];           // [yaw, pitch, roll]   yaw/pitch/roll container and gravity vector
  float acc[3];           // [x, y, z]   yaw/pitch/roll container and gravity vector
  
  boolean mpuInterrupt = false;
  // packet structure for InvenSense teapot demo
  uint8_t teapotPacket[14] = { '$', 0x02, 0,0, 0,0, 0,0, 0,0, 0x00, 0x00, '\r', '\n' };

//#define printf(...) 
#endif

void setup() {
 //   Serial1.begin(19200);

  r = 255;
  g = 0;
  b = 0;
  pixels.begin(); // This initializes the NeoPixel library.
  setPixel(0,0,0,0);
  
  
  // MPU6050 Init
  Wire.begin();
  TWBR = 24; 
  mpu.initialize();
  printf("%s\n",mpu.testConnection() ? "[MPU6050] connection successful" : "[MPU6050] connection failed");
  
  if (!mpu.testConnection()) return;
  
  devStatus = mpu.dmpInitialize();
  printf("[MPU6050] MPU Status: %d\n", devStatus);

  // supply your own gyro offsets here, scaled for min sensitivity
  mpu.setXGyroOffset(220);
  mpu.setYGyroOffset(76);
  mpu.setZGyroOffset(-85);
  mpu.setZAccelOffset(1788); // 1688 factory default for my test chip
  mpu.setDMPEnabled(true);
  
  packetSize = mpu.dmpGetFIFOPacketSize();
  
  
  DDRB &= ~(1 << DDB5);
  PORTB |= (1 << PORTD5);
  PCICR |= (1 << PCIE0);
  PCMSK0 |= (1 << PCINT5);
    
}

void loop() {
  mpu6050();
}

void setPixel(int id, char r, char g, char b){
   pixels.setPixelColor(id, pixels.Color(r,g,b));
   pixels.show(); 
}


char mpu6050(){
    if (devStatus != 0) return -1;
    if (!mpuInterrupt && fifoCount < packetSize) return 0;

    mpuInterrupt = false;
    mpuIntStatus = mpu.getIntStatus();
    fifoCount = mpu.getFIFOCount();
    
    if ((mpuIntStatus & 0x10) || fifoCount == 1024) {
        mpu.resetFIFO();
        printf("[MPU6050] FIFO overflow!");
    } else if (mpuIntStatus & 0x02) {
        while (fifoCount < packetSize) fifoCount = mpu.getFIFOCount();
        mpu.getFIFOBytes(fifoBuffer, packetSize);
       
        fifoCount -= packetSize;
        
      mpu.dmpGetQuaternion(&q, fifoBuffer);
      mpu.dmpGetGravity(&gravity, &q);
      mpu.dmpGetYawPitchRoll(ypr, &q, &gravity);
      mpu.dmpGetEuler(euler, &q);
      
      
      mpu.dmpGetAccel(&aa, fifoBuffer);
      mpu.dmpGetLinearAccel(&aaReal, &aa, &gravity);
      acc[0] = aaReal.x;
      acc[1] = aaReal.y;
      acc[2] = aaReal.z;
      
      return 1;
    }
    
  return 0;
}

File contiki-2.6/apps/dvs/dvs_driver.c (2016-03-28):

#include <math.h>

#include "contiki.h"

#include "cfs/cfs.h"
#include "cfs/cfs-coffee.h"
#include "cfs-coffee-arch.h"

#include "dvs.h"

char current_prog, selected_prog;
int fd = -1;
int speed = 1000;

/*---------------------------------------------------------------------------*/
void dvs_init(){
  DDRD  |= 1 << PIN4;
  PORTD ^= (1 << PIN4);
  // Format the File System if first boot
  int fa = cfs_open("/init", CFS_WRITE);
  cfs_write(fa, "init\0", 6);
  cfs_close(fa);


  neopixel_init();
  current_prog = selected_prog = 0;

  // Configuration of button interruption on PB4
  DDRB &= ~(1 << DDB4);
  PORTB |= (1 << PORTD4);
  PCICR |= (1 << PCIE0);
  PCMSK0 |= (1 << PCINT4);
  sei();
}
/*---------------------------------------------------------------------------*/
/* Button management:
1 released click: play next program
5 seconds of pressure: formatting eeprom memory
*/
/*---------------------------------------------------------------------------*/
char btn_state = 0;
extern char mpuInterrupt;
volatile uint8_t portbhistory = 0x00;

PROCESS(dvs_format, "DVS cfs format process");
PROCESS_THREAD(dvs_format, ev, data)
{
  static struct etimer periodic_timer;
  char i;

  PROCESS_BEGIN();
  etimer_set(&periodic_timer, CLOCK_SECOND*20);
  PROCESS_WAIT_EVENT_UNTIL(etimer_expired(&periodic_timer));

  if (btn_state == 1){
    printf("Formatting\n");
    for (i = 0; i < NUM_LEDS; i++)
      setPixel(i, 255,0,0);

    cfs_coffee_format();

    for (i = 0; i < NUM_LEDS; i++)
      setPixel(i, 0,255,0);
  }
  PROCESS_END();
}

ISR (PCINT0_vect)
{
    uint8_t changedbits;

    changedbits = PINB ^ portbhistory;
    portbhistory = PINB;

   // MPU 6050 Interruption
   if (changedbits & (1 << PB5))
    mpuInterrupt = 1;

    // External button
    else if (changedbits & (1 << PB4)) {
     // Start process to count long pression

     if (btn_state == 0)
      process_start(&dvs_format, NULL);

     if(++btn_state % 2) return;
     btn_state = 0;

     if(!(++selected_prog % (MAX_PROGRAMS + 1 ) )) selected_prog = 0;
     printf("DVS plays program %d\n", selected_prog);

     if (selected_prog == 4){
       if (process_is_running (&dvs_player))  process_exit(&dvs_player);
     	 process_start(&dvs_mpu6050, NULL );
     }
     else {
       if (process_is_running (&dvs_mpu6050))  process_exit (&dvs_mpu6050);
       process_start(&dvs_player, NULL);
       speed = 1000;
     }
    }
}



/*---------------------------------------------------------------------------*/
/*---------------------------------------------------------------------------*/
/*---------------------------------------------------------------------------*/
char prev = 0;
char mpu6050_show = 0;
PROCESS(dvs_mpu6050, "DVS dvs_mpu6050");
PROCESS_THREAD(dvs_mpu6050, ev, data)
{
  static struct etimer periodic_timer;

  PROCESS_EXITHANDLER(mpu6050_show = 0;)

  PROCESS_BEGIN();

  if (strncmp(data,"show", 4) == 0)
    mpu6050_show = 1;

  etimer_set(&periodic_timer, 0);

  while(1) {
    PROCESS_WAIT_EVENT_UNTIL(etimer_expired(&periodic_timer));
    etimer_reset(&periodic_timer);

    // MPU6050 loop function
    if(mpu6050()){
        if (mpu6050_show == 1){
            printf("ypr %f %f %f \n", ypr[0]* 180/M_PI, ypr[1]* 180/M_PI, ypr[2]* 180/M_PI);
            printf("acc %f %f %f \n", acc[0], acc[1], acc[2]);
            printf("Euler angle %f %f %f \n", euler[0]* 180/M_PI, euler[1]* 180/M_PI, euler[2]* 180/M_PI);
          }

        if (ypr[1]* 180/M_PI < -75){
          if(prev != 0) {
            neopixel_init();
            setPixel(3, 255, 0, 0);
            setPixel(4, 255, 0, 0);
          }
          prev = 0;
        }
        else if (ypr[1]* 180/M_PI < -45){
          if(prev != 1) {
            neopixel_init();
            setPixel(2, 255, 0, 0);
            setPixel(5, 255, 0, 0);
          }
          prev = 1;
        }
        else if (ypr[1]* 180/M_PI < -25){
          if(prev != 2) {
            neopixel_init();
            setPixel(1, 255, 0, 0);
            setPixel(6, 255, 0, 0);
          }
          prev = 2;
        }
        else if (ypr[1]* 180/M_PI < 0){
          if(prev != 3) {
            neopixel_init();
            setPixel(0, 255, 0, 0);
            setPixel(7, 255, 0, 0);
          }
          prev = 3;
        }

        else  if (ypr[1]* 180/M_PI > 75){
          if(prev != 4) {
            neopixel_init();
            setPixel(11, 255, 0, 0);
            setPixel(12, 255, 0, 0);
          }
          prev = 4;
        }
        else  if (ypr[1]* 180/M_PI > 45){
          if(prev != 5) {
            neopixel_init();
            setPixel(10, 255, 0, 0);
            setPixel(13, 255, 0, 0);
          }
          prev = 5;
        }
        else  if (ypr[1]* 180/M_PI > 25){
          if(prev != 6) {
            neopixel_init();
            setPixel(9, 255, 0, 0);
            setPixel(14, 255, 0, 0);
          }
          prev = 6;
        }
        else if (ypr[1]* 180/M_PI > 0){
          if(prev != 6) {
            neopixel_init();
            setPixel(8, 255, 0, 0);
            setPixel(15, 255, 0, 0);
          }
          prev = 6;
        }
      }
    //printf("Euler angle %f %f %f \n", euler[0]* 180/M_PI, euler[1]* 180/M_PI, euler[2]* 180/M_PI);
    }
  PROCESS_END();
}

/*---------------------------------------------------------------------------*/
/*---------------------------------------------------------------------------*/
/*---------------------------------------------------------------------------*/
/** Process to start a set of sequences to test the leds
 * Each led successively turn on from red, green and blue
 */

PROCESS(neopixel_test_process, "Neopixel test");
PROCESS_THREAD(neopixel_test_process, ev, data)
{
  static struct etimer periodic_timer;
  static unsigned char r,g,b;
  static short int count;

  PROCESS_BEGIN();
  r = 255;
  g = b = 0;
  count = 0;

  printf("Neopixel Test Initialized\n");
  etimer_set(&periodic_timer, CLOCK_SECOND/8);
  while(1) {
    if (count >= NUM_LEDS*4)
      PROCESS_EXIT();




    PROCESS_WAIT_EVENT_UNTIL(etimer_expired(&periodic_timer));
    etimer_reset(&periodic_timer);

    setPixel(count % NUM_LEDS, r, g, b);
    count ++;

    if (count % NUM_LEDS == 0) {
      if (r == 255){
        r = b = 0;
        g = 255;
      }
      else if (g == 255){
        g = r = 0;
        b = 255;
      }
      else r = g = b = 0;
    }
  }
    PROCESS_END();
}



void neopixel_init(){
  int i;
  for (i=0; i < NUM_LEDS; i++)
    setPixel(i, 0,0,0);
}

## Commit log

2016-03-26 [IMPORT] DVS Software - v0.1
    Hardware: 8-Bit AVR Atmega128rfa1 IEEE 802.15.4
    Operating System
    * Contiki 2.6 / HTTP RestFul API / Coffee File System / Serial Shell / 6loWPAN (no RPL)
    * MPU6050 Accelerometer Arduino Driver embedded in Dynamic Library
    * Adafruit Neopixel Arduino Driver embedded in Dynamic Library
    Functionnalities:
    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
    [1000pkt-64len.csv, arm7_wig.cfg, arm7_wig_flash.cfg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]
2016-03-26 [BIN] Add binary file of compiled Arduino library * Neopixel Driver * MPU6050 Driver
2016-03-28 [NEW & FIX] Program 4 play leds according to accelerometer / Fix bug of interruptions between MPU6050 and external button
    [dvs_arduino.ino, dvs_driver.c]
2016-03-28 [HARDWARE] Scheme, routing, component list and design rules
    [child.brd, child.sch, master.brd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]
